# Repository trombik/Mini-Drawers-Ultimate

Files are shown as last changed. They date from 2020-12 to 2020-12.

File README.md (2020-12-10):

# Mini Drawers Ultimate

This repository contains OpenSCAD files from [Mini Drawers Ultimate](https://www.thingiverse.com/thing:1889761).

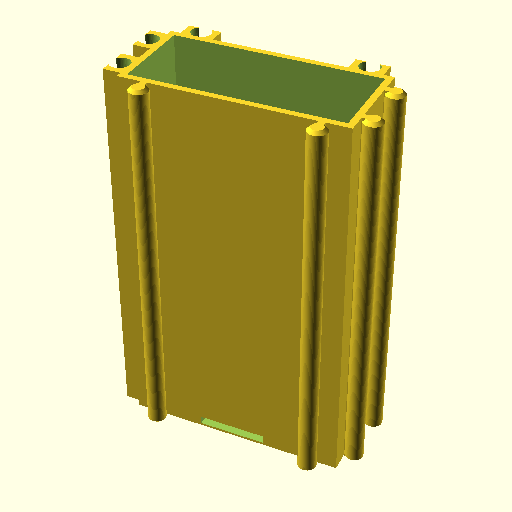
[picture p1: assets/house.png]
House

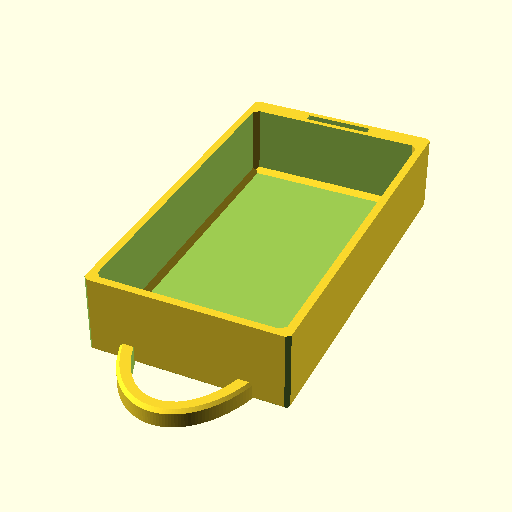
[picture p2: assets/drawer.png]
Drawer


`1x1` is great for through-hole transistors, 8 pin DIP ICs. `2x1` is just
enough size for through-hole resistors, diodes, and 28 pin DIP ICs.

## Rationale

Thingiverse does not encourage designers to share original code or files.
Often, designers uploads STL files only. Some, including the author of the
original design, upload original files so that others can re-mix the original,
fix bugs, adopt the design. However, it is really difficult to track changes,
report bugs, etc. I tried to rebuild STL files without success. The code uses
an external library, but the author did not include the library, nor mention
the version.  The code should be managed in Version Management System.

## Requirements

- openscad
- BSD make (optional, not GNU make)
- X server (optional)

## Usage

```console
git clone https://github.com/trombik/Mini-Drawers-Ultimate.git
cd Mini-Drawers-Ultimate
env OPENSCADPATH=src/lib/Chamfers-for-OpenSCAD openscad src/drawer.scad
env OPENSCADPATH=src/lib/Chamfers-for-OpenSCAD openscad src/house.scad
```

Or simply:

```console
make
```

If you want 2x1 version, then:

```console
make XY_FLAGS="-D num_x=2 -D num_y=1"
```

The command above creates `house.stl`, `house.png`, `drawer.stl`, and
`drawer.png`. As `OpenSCAD` cannot export images without X screen, X server is
required.

## Defaults

- Drawer and house have drop-in magnet holes. Removing them does not save much
  space.
- No slot partition. It does not make sense because 1) the partitioned space
  is too small for anything, 2) it would be hard to find parts when one drawer
  has multiple parts.
- Magnet hole is 10 mm diameter and 0.8 mm thickness, which is commonly
  available.
- One handle per drawer

If the defaults do not work for you, `make` variables can be overridden. Or,
do not use the `Makefile`.

## STL files

The [Releases](../../releases) page has STL files of the pair in various sizes.

## Tips

The drawer is very easy to print. The house is more difficult. PLA works fine.

Use magnets. They are cheap, and you will appreciate them.

When the runner of house is not printed well, try 0% infill. The infill often
creates nonuniform shape. Even without infill, the strength is just enough.

Bad shaped runner can be fixed by a small electric drill and carving bits.

Be sure to avoid stringing. Stringing produces bad prints. See [Cura
Retraction Settings: How to Avoid Stringing](https://all3dp.com/2/cura-retraction-settings-how-to-avoid-stringing/).

In addition to custom retraction settings, disabling combing in Travel setting
produces better results. See [Travel settings](https://support.ultimaker.com/hc/en-us/articles/360012611299-Travel-settings).

Layer hight should be 0.2 mm. 0.1 mm layer hight produces better prints, but
unacceptably long to print. For example, 2x2 house takes 7 hours with 0.1 mm,
3.5 hours with 0.2 mm.

## Authors

- [Trevor Moseley](https://www.thingiverse.com/trevm/designs) (all the work)
- [Tomoyuki Sakurai](https://github.com/trombik) (repository maintenance and
  CI)

## License

[Attribution 4.0 International (CC BY 4.0)](https://creativecommons.org/licenses/by/4.0/).
See [LICENSE](LICENSE) for details.

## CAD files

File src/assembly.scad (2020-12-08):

// scad code to render the house and drawer together, either for fit preview, or together for printing
//
// code originally by zeropage. rewritten by ofloveandhate sep2017

include <house.scad>;
include <drawer.scad>;

// ====== EDIT ==========================
// these will override the values set in the drawer and house files.
num_x = 4;
num_y = 4;
use_label = true;
drawer_label = ["printer parts",7,"Liberation Sans:style=Bold",0.5];
use_magnet = true;
magnet_is_droppedin = true; // NOTE: if you use drop-in magnets you must uncomment lines in the house.scad file
// ======================================

to_print = true;
cut = true;

slot_partition = [1]; // partition of the unit interval into slots.  valid partitions add up to something ≤ 1

if (!to_print)
{
  if (cut)
    cut_to_display();
  else
    assembled_unit();
}

module assembled_unit()
{
  drawer_slideout = 10;
  union()
  {
    translate([interior_unit_width*(num_x)-runnersDiameter,house_depth,(num_y)*interior_unit_height-runnersDiameter])
      rotate([-90,0,180])
        house();

    translate([house_wall_thickness_s+inset_width,-drawer_slideout+inset_depth/2,house_wall_thickness_s + inset_height/2])
      drawer();
  }
}

module cut_to_display()
{
  difference()
  {
    assembled_unit();
    cutting_object();
  }
}


module cutting_object()
{
  translate([-10,50,40])
    rotate([45,45,0])
      cube([100,100,100]);
}

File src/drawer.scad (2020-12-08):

// scad code for modular minidrawer -- drawer part
// code originally by zeropage. rewritten by ofloveandhate sep2017

include <Chamfer.scad>; // https://github.com/SebiTimeWaster/Chamfers-for-OpenSCAD/

drawer_label = ["test",4,"Liberation Sans:style=Bold",0.5];
use_label = true;

$fn = 50;
ang = 25;

// ======= EDIT ======================
num_x = 1;
num_y = 2;
slot_partition = [.33,.33, .34];//[0.4,0.6]; // partition of 1 into slots
use_magnet = false;
magnet_is_droppedin = false;
// ===================================

// ideally these numbers come directly from the house parameters.
house_wall_thickness_s = 1;
house_wall_thickness_b = 1;
house_depth = 56;
unit_height = 17.9;
unit_width = 35.9;
space_width = 4.9;
space_height = 4.9;


// thicknesses of things
drawer_wall_thickness_x = 1.2;
drawer_wall_thickness_f = 1.2;
drawer_wall_thickness_b = 3; // shoule be thicker than magnet_h plus extrusions, if using slot for magnet
drawer_wall_thickness_s = 1.2; // thickness of walls between slots
drawer_floor_thickness = 1;

// space to leave between the walls of the drawer and house
inset_width = 0.5;
inset_height = 0.6;
inset_depth = 0.5;



chamfer_interior = 0.8;
chamfer_exterior = 0.6;
should_chamfer_top = 0; // a boolean 1 or 0

magnet_r = 4.15;
magnet_h = 1.25;

use_num_x_handles = true; // false generates a single handles in the middle

eps = 0.01;





to_print = true;

if (to_print)
{
  translate([0,-drawer_depth-10,0])
  drawer();
}
else
  ;


module drawer()
{
  difference()
  {
    drawer_positive();
    drawer_negative();
  }

  handles();
}

drawer_depth = house_depth - 1*house_wall_thickness_b - inset_depth;// including walls
drawer_width = unit_width*num_x -space_width - 2*inset_width;
drawer_height = unit_height*num_y - space_height+0.8 - inset_height;

module drawer_positive()
{
  usable_height = drawer_height - drawer_floor_thickness;
  chamferCube(drawer_width,drawer_depth,usable_height,chamfer_exterior,[1,1,should_chamfer_top,should_chamfer_top],[1,should_chamfer_top,should_chamfer_top,1],[1,1,1,1]);
  if ( use_label ) label();
}

module drawer_negative()
{

  num_slots = len(slot_partition);

  interior_w = drawer_width - 2*drawer_wall_thickness_x;

  x = drawer_wall_thickness_f;

  usable_depth = drawer_depth - drawer_wall_thickness_f - drawer_wall_thickness_b - (
  num_slots-1)*drawer_wall_thickness_s;

  usable_height = drawer_height - drawer_floor_thickness;

  for (ii = [0:num_slots-1])
  {
    depth_this = slot_partition[ii]*usable_depth;
    y_this = 0;
    used_prev = add(slot_partition, 0, num_slots-ii);
    bla = used_prev*usable_depth+ii*drawer_wall_thickness_s + drawer_wall_thickness_f;

    translate([drawer_wall_thickness_x,bla,drawer_floor_thickness])
      chamferCube(interior_w,depth_this,usable_height,chamfer_interior,[1,1,0,0],[1,0,0,1],[1,1,1,1]);
  }

  if (num_slots>1)
  {
    for (jj = [0:num_x-1]){
      for (ii = [1:num_slots-1])
      {
        depth_this = slot_partition[ii]*usable_depth;
        y_this = 0;
        used_prev = add(slot_partition, 0, num_slots-ii);
        //		echo(used_prev);
        bla = used_prev*usable_depth+ii*drawer_wall_thickness_s + drawer_wall_thickness_f - drawer_wall_thickness_s*1.5;
        //drawer_width/(num_x)*(jj) + 14/2
        translate([8 +jj*35.9,bla,usable_height-1.29])
        {
          chamferCube(14,2,1.3,1.5,[],[1,0,0,1],[]);
        }
      } // for ii
    } // jj
  } // if
  if (use_magnet)
    drawer_magnet_cutouts();
}

function add(cont, ii=0, off_b=0, val=0) = ii<len(cont)-off_b ? add(cont, ii+1, off_b, val+cont[ii]) : val;

module drawer_magnet_cutouts()
{
  for (ii = [0:num_x-1])
  {
    if (magnet_is_droppedin)
      translate([ii*35.9+15,drawer_depth - drawer_wall_thickness_b/2-magnet_h/2,0])
        drawer_magnet_cutout_single();
    else
      translate([ii*35.9+15,drawer_depth-magnet_h+eps,0])
        drawer_magnet_cutout_single();
  }
}



module drawer_magnet_cutout_single()
{
  translate([0,0,drawer_height/2])
  {
    translate([0,0,0])
      rotate([-90,0,0]) cylinder(h=magnet_h+eps,r=magnet_r,$fn=100); // top hole for magnet
    if (magnet_is_droppedin)
      translate([-magnet_r,-eps,0])
        cube([magnet_r*2, magnet_h+2*eps, drawer_height/2]); // top hole for magnet
  }

}

module handles()
{
  if (use_num_x_handles)
  for (ii=[0:num_x-1])
    translate([ii*35.9+15,0,0])
      handle();

  else
     translate([drawer_width/2,0,0])
      handle();
}


module handle()
{
  difference() {
    translate([0,8,0]) chamferOval(11,18,3);
    translate([0,8,-0.1]) oval(9,16,3.2);
    translate([-11-2,0.1,-0.1])	cube([29.8,30,3.2]);
  }
}

module oval(w,h, height, center = false) {
  scale([1, h/w, 1]) cylinder(h=height, r=w, center=center);
}

module chamferOval(w,h, height) {
  scale([1, h/w, 1]) chamferCylinder(height, w, w, .4, .4, 360);
}


module label()
{
/* original code from dani      translate([drawer_width/2-len(drawer_label[0])/2*drawer_label[1]*0.6,0,drawer_height/2])
    rotate([90,0,0])
      linear_extrude(height=drawer_label[3])
        text(drawer_label[0], font=drawer_label[2], size=drawer_label[1]);
*/
/* as suggested by Bolukan */
translate([drawer_width/2,0,drawer_height/2+0.75])
rotate([90,0,0])
linear_extrude(height=drawer_label[3])
text(drawer_label[0], font=drawer_label[2], size=drawer_label[1], halign="center", valign="center");
}

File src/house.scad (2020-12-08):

// scad code for modular minidrawer -- house part
// code originally by zeropage. rewritten by ofloveandhate sep2017

include <Chamfer.scad>; // https://github.com/SebiTimeWaster/Chamfers-for-OpenSCAD/
$fn = 50;
house_wall_thickness_b = 1;
house_depth = 56; // in millimeters. this is the depth of the unit against the wall, front to back, including walls.

// ======= EDIT ================
num_x = 2;  // width
num_y = 2;  // height
use_magnet = false; // true to use magnets
//magnet_is_droppedin = true; // true to get drop-in slot for the magnet
//house_wall_thickness_b = 2; // MUST uncomment if drop-in magnets used, else the backwall will be too thin
//house_depth = 57; // MUST uncomment if drop-in magnets used, else the drawers will stand out by 1mm
magnet_r = 4.15;
magnet_h = 1.25; // the back wall should be at least this thick if using dropped in magnet
// ===============================

house_wall_thickness_s = 1;

interior_unit_width = 35.9;
interior_unit_height = 17.9;

chamfer_runners = 0.5;
runnersDiameter = 2.85;
runner_joincube_width = 1;

slot_thickness = 2.8;
slot_width = 5;
slot_gap = 0.25 ; // extra space between the runner cylinder, and the slot receiver. this number is a difference in diameters, so this difference is NOT the total gap all around, that's half this number.
slot_cylinder_inset = 0.1;
slot_inset_from_box_x = 1.5;
slot_inset_from_box_y = 1;

runner_offset_x = 25;
runner_offset_y = 8;

stopper_height = 2;  // how far off the top wall the stopper should project
stopper_length = 10;
stopper_width = 10;
stopper_inset = 2;
stopper_faces_front = false;  // which side the flat face of the stoppers should be on.  if true, the flat face is toward the front of the housing.


eps = 0.01;

to_print = true;




///////////utility computations

inter_house_offset = house_wall_thickness_s*2 + runnersDiameter; // 4.9 is old version
house_box_height = num_y*interior_unit_height - inter_house_offset;
house_box_width = num_x*interior_unit_width - inter_house_offset;
inter_drawer_offset = (runnersDiameter+slot_gap/2);

////////////  end utility computations


if (to_print)
  house();
else
{
//  house(); // display mode in the assembly

//  translate([-house_box_width - inter_house_offset,0,0])
//    house();
//
//  translate([house_box_width + inter_house_offset,0,0])
//    house();
//
//  translate([0,-house_box_height - inter_house_offset,0])
//    house();
//
//  translate([0,+house_box_height + inter_house_offset,0])
//    house();
}

module house()
{
  difference() {
    house_positive();
    house_negative();
  }
}


module house_negative()
{
  q = house_wall_thickness_s*2 + runnersDiameter; // 4.9 for 100% compatibility w old versions
  difference(){
    translate([house_wall_thickness_s,house_wall_thickness_s,house_wall_thickness_b])
      cube([interior_unit_width*num_x-q, interior_unit_height*num_y-q, house_depth]);
    stoppers();
  }
  if (use_magnet)
    house_magnet_cutouts();
}


module house_magnet_cutouts()
{
  if (magnet_h >= 1*house_wall_thickness_b && magnet_is_droppedin)
  {
    echo("magnet thickness very near to back wall thickness.  things probably not as desired");
  }

  for (ii = [0:num_x-1])
  {
    if (magnet_is_droppedin)
    {
      translate([ii*interior_unit_width+16,0,house_wall_thickness_b/2-magnet_h/2])
        magnet_cutout_single();
    }
    else
    {
      translate([ii*interior_unit_width+16,0,house_wall_thickness_b-magnet_h])
        magnet_cutout_single();
    }
  }
}



module magnet_cutout_single()
{
  translate([0,house_box_height/2, 0 ])
  {
    magnet();
    if (magnet_is_droppedin)
    {
      magnet_cutout_slot();
    }
  }
}

module magnet()
{
  translate([0,0,0])
    rotate([0,0,0]) cylinder(h=magnet_h+eps,r=magnet_r,$fn=100);
}

module magnet_cutout_slot()
{
  c = house_box_height/2+2*eps;
  translate([-magnet_r,-house_box_height/2-eps,0])
    cube([magnet_r*2, c , magnet_h+eps ]); // top hole for magnet
  // the eps here are to ensure the cube protrudes from the top of the house
}



module stoppers()
{
for (ii = [0:num_x-1])
  translate([ii*interior_unit_width,0,0])
    stopper();
}

module stopper()
{
  translate([stopper_width,stopper_height+house_wall_thickness_s-eps,house_depth-stopper_inset])
    rotate( [0,180,180] )
      prism(l=stopper_length+stopper_height,w=stopper_height,h=stopper_length);
}



module house_positive()
{
  q = runnersDiameter; // 2.9 for 100% compatibility with old versions, though the difference is quite small (0.05)

  overall_x = interior_unit_width*num_x-q;
  overall_y = interior_unit_height*num_y-q;
  cube([overall_x, overall_y,house_depth]);

  radius = runnersDiameter/2;

  for (ii=[0:num_x-1])
    translate([interior_unit_width*ii,0,0])
    {
      runner_bottom();
      translate([runner_offset_x, 0, 0])
        runner_bottom();

      translate([0,overall_y-interior_unit_height+q,0])
      {
        slot_top();
        translate([runner_offset_x,0,0])
          slot_top();
      }
    }

  for (jj=[0:num_y-1])
    translate([0,interior_unit_height*jj,0])
    {
      translate([overall_x-(interior_unit_width-runnersDiameter),0,0])
      {
        runner_right();
        translate([0,8,0])
          runner_right();
      }
      translate([0,0,0])
      {
        slot_left();
        translate([0,runner_offset_y,0])
          slot_left();
      }
    } // for jj's translate

}




module slot_top()
{
  slot_diameter = runnersDiameter + slot_gap;
  difference()
  {
    translate([ slot_inset_from_box_x,  15-slot_cylinder_inset, 0]) cube([slot_width,slot_thickness,house_depth]);
    translate([ (slot_width/2+slot_inset_from_box_x),  16.5, -eps]) cylinder(d=slot_diameter,h=house_depth+2*eps);
  }
}

module runner_bottom()
{
  runner_cylinder_inset_bottom = 0.025;
  radius = runnersDiameter/2;

  x = slot_width/2+slot_inset_from_box_x;
  y = radius-runner_cylinder_inset_bottom;

  translate([ x,  -y, 0]) chamferCylinder(house_depth,radius,radius,chamfer_runners);
  translate([x-runner_joincube_width/2,-(y-eps), 0]) cube([runner_joincube_width,radius,house_depth]);
}


module slot_left()
{
  slot_diameter = runnersDiameter + slot_gap;
  translate([0,0,0])
  difference()
  {
    q = runnersDiameter/2+slot_cylinder_inset;
    translate([- (slot_thickness - slot_cylinder_inset),   slot_inset_from_box_y,   0]) cube([slot_thickness,slot_width,house_depth]);
    translate([-q, slot_inset_from_box_y + slot_width/2, -eps]) cylinder(d=slot_diameter,h=house_depth+2*eps);
  }

}


module runner_right()
{

  radius = runnersDiameter/2;
  translate([(interior_unit_width-runnersDiameter/2), slot_inset_from_box_y + slot_width/2,0]) chamferCylinder(house_depth,radius,radius,chamfer_runners);

  x = (interior_unit_width-runnersDiameter)-eps;
  y = slot_inset_from_box_y + slot_width/2-runner_joincube_width/2;
  translate([x, y,  0]) cube([radius,runner_joincube_width,house_depth]);
}







module prism(l, w, h)
{
  p_front = [[0,0,0], [l,0,0], [l,w,0], [0,w,0], [0,w,h], [l,w,h]];
  p_back = [[0,0,h], [l,0,h], [l,w,0], [0,w,0], [0,w,h], [l,w,h]];

  f = [[0,1,2,3],[5,4,3,2],[0,4,5,1],[0,3,4],[5,2,1]];

  if (stopper_faces_front)
  {
    polyhedron(
      points=p_front,
      faces=f
    ); 
  }
  else
  {
    polyhedron(
      points=p_back,
      faces=f
    ); 
  }

}

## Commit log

2020-12-08 initial import
    [assembly.scad, drawer.scad, house.scad]
2020-12-08 bugfix: follow changes in the library, fixes missing handle
    [drawer.scad]
2020-12-08 ci: add Github Actions workflow to build STL files
2020-12-09 doc: add another tip to fix bad prints
2020-12-10 doc: document published STL files
2020-12-10 bugfix: s/1 mm/0.8 mm/
